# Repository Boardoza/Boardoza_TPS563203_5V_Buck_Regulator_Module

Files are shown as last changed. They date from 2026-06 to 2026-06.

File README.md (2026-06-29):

# Boardoza TPS563203 5V Regulator Module

The **Boardoza TPS563203 5V Regulator Module** is a compact and efficient DC-DC buck (step-down) converter designed to provide a stable **5V output** from a wide **7V–17V DC input** range. It is based on the **Texas Instruments TPS563203** synchronous buck regulator, known for its high efficiency and low quiescent current.

This module is ideal for powering **microcontrollers, sensors, communication modules, and embedded systems** that require a reliable 5V supply from higher-voltage sources such as adapters, batteries, or industrial power rails. Its small form factor and robust thermal performance make it suitable for both prototyping and production use.

## [Click here to purchase!](https://www.ozdisan.com/ureticiler/boardoza)

| Front Side | Back Side |
|:---:|:---:|
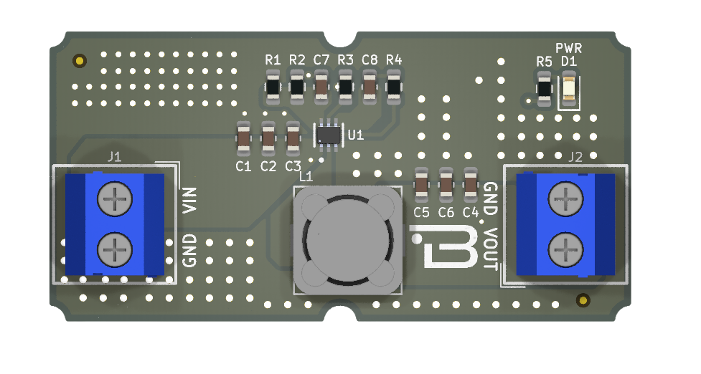
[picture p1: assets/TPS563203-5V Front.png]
TPS563203 5V Front
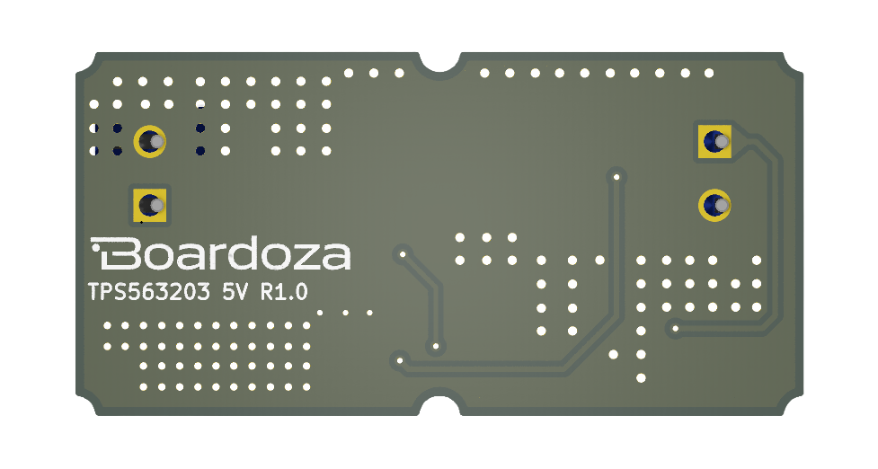
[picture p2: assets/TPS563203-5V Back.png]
TPS563203 5V Back
|  |  |

---

## Key Features

- **Wide Input Voltage Range:** Supports 7V to 17V DC input for flexible power sources.  
- **Stable 5V Output:** Provides a fixed and regulated 5V DC output suitable for logic and embedded systems.  
- **High Output Current Capability:** Delivers up to 2A continuous output current.  
- **High Efficiency Buck Topology:** Synchronous step-down conversion for reduced power loss.  
- **Low Quiescent Current:** Optimized for power-efficient designs with minimal standby consumption.  
- **Integrated Soft-Start:** Ensures controlled startup to protect connected loads.

---

## Technical Specifications

**Model:** TPS563203 5V  
**Manufacturer:** Boardoza  
**Manufacturer IC:** Texas Instruments  
**Regulator Type:** DC-DC Buck (Step-Down) Converter  
**Input Voltage:** 7V – 17V DC  
**Output Voltage:** 5V DC  
**Output Current:** Up to 2A  
**Switching Frequency:** 600 kHz  
**Quiescent Current:** 110 µA (typ.)  
**Soft-Start Time:** 1.4 ms (fixed)  
**Reference Voltage Accuracy:** ±1.5% (25°C), ±2% (–40°C to +125°C)  
**Operating Temperature:** –40°C to +125°C  
**Board Dimensions:** 20 mm × 40 mm  

---

## Board Pinout

### **( J1 ) Input Connector**

| Pin Number | Pin Name | Description |
|:---:|:---:|---|
| 1 | VIN | DC Input Voltage (7V – 17V) |
| 2 | GND | Ground |

### **( J2 ) Output Connector**

| Pin Number | Pin Name | Description |
|:---:|:---:|---|
| 1 | VOUT | Regulated +5V Output |
| 2 | GND | Ground |

---

## Board Dimensions

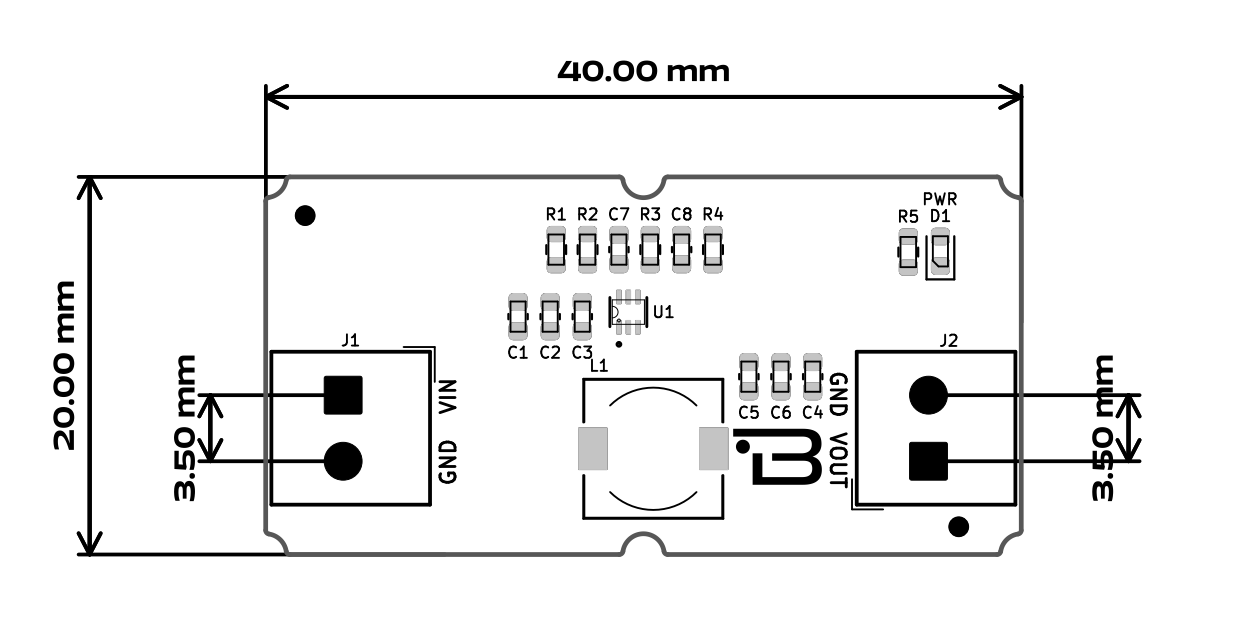
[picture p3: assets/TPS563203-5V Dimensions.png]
Board Dimensions
  

---

## Step Files

[Boardoza TPS563203 5V.step](./assets/TPS563203-5V%20Step.step)

---

## Datasheet

[TPS563203 5V Datasheet.pdf](./assets/TPS563203-5V%20Datasheet.pdf)

---

## Version History

- **V1.0.0** – Initial Release

---

## Support

- If you have any questions or need support, please contact **support@boardoza.com**

---

## **License**
### **Hardware Design**

[][cc-by-sa]

All hardware design files are licensed under [Creative Commons Attribution-ShareAlike 4.0 International License][cc-by-sa].

[cc-by-sa]: http://creativecommons.org/licenses/by-sa/4.0/
[cc-by-sa-shield]: https://img.shields.io/badge/License-CC%20BY--SA%204.0-lightgrey.svg

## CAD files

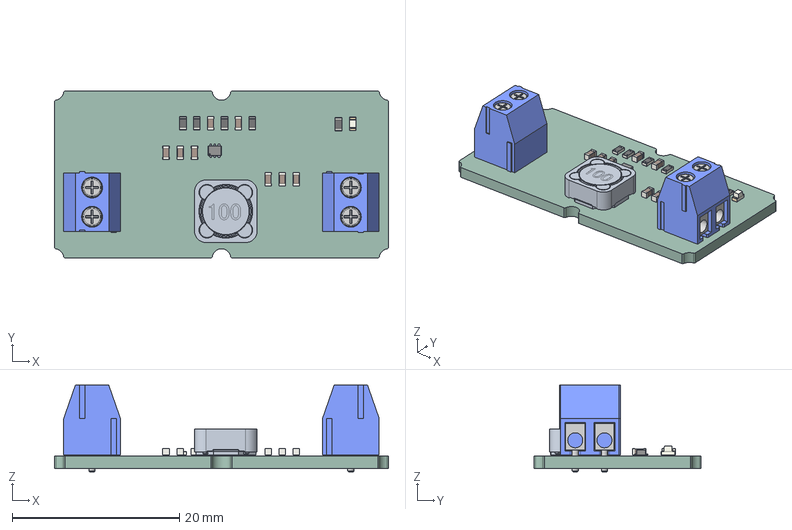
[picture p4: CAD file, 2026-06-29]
assets/TPS563203-5V Step.step
40.0 x 20.0 x 10.4 mm
Screw Terminal Block 3.5mm Blue 2-way x 2
LED_0603_1608Metric
R_0603_1608Metric x 5
C_0603_1608Metric x 8
SRR1260A-681K
TPS563203DRLR (1)
B-TPS563203-5V-BRK_PCB

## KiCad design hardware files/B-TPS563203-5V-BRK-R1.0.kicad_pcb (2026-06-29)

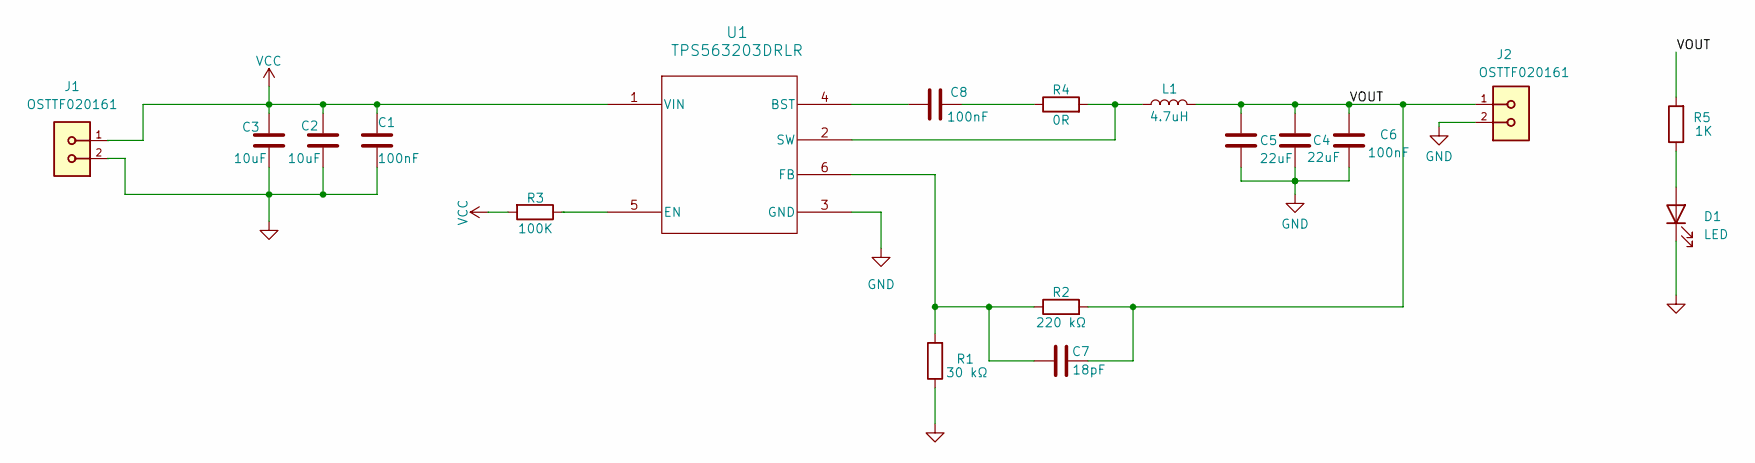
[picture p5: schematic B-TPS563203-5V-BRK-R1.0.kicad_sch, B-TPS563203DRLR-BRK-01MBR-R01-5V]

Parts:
C1, C6, C8: 100nF; C_0603_1608Metric; MPN CL10B104KB8NNNC
C2, C3: 10uF; C_0603_1608Metric; MPN MCF03MTX250106
C4, C5: 22uF; C_0603_1608Metric; MPN GRM188R61A226ME15D
C7: 18pF; C_0603_1608Metric; MPN MCF03JTN500180
D1: LED; LED_0603_1608Metric; MPN LTST-C190KRKT
J1, J2: OSTTF020161; OST_OSTTF020161; MPN DG350-3.5-02P-12-00AH
L1: 4.7uH; L_7.3x7.3_H4.5; MPN SRI0704-4R7M
R1: 30 kΩ; R_0603_1608Metric; MPN 0603SAJ0303T5E
R2: 220 kΩ; R_0603_1608Metric; MPN CRT03F7E2203
R3: 100K; R_0603_1608Metric; MPN CRT03F7E1003
R4: 0R; R_0603_1608Metric; MPN CRT03J7-R0R0
R5: 1K; R_0603_1608Metric; MPN RC0603JR-071KL
U1: TPS563203DRLR; SOT_07SDRLR_TEX; MPN TPS563203DRLR

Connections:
/VOUT: C4.1, C5.1, C6.1, C7.2, J2.1, L1.2, R2.2, R5.2
GND: C1.2, C2.2, C3.2, C4.2, C5.2, C6.2, D1.1 (K), J1.2, J2.2, R1.1, U1.3 (GND)
unnamed: C8.1, R4.1
unnamed: D1.2 (A), R5.1
unnamed: C8.2, U1.4 (BST)
unnamed: R3.1, U1.5 (EN)
unnamed: C7.1, R1.2, R2.1, U1.6 (FB)
unnamed: L1.1, R4.2, U1.2 (SW)
VCC: C1.1, C2.1, C3.1, J1.1, R3.2, U1.1 (VIN)

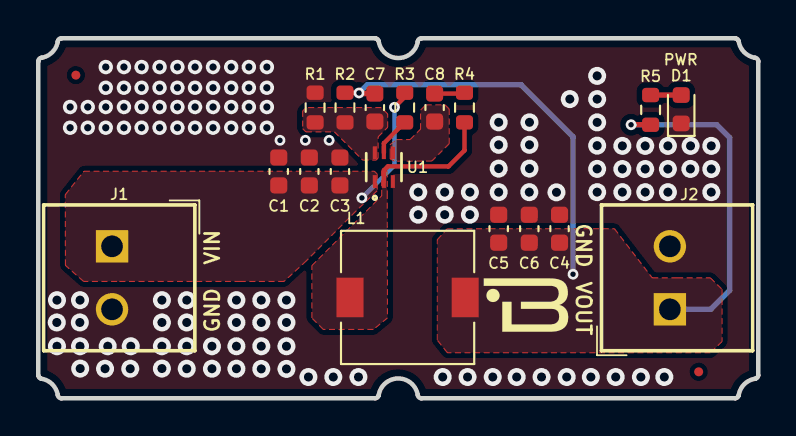
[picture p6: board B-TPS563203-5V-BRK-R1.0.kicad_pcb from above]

Board: 2 copper layers, 40.0 x 20.0 mm, 18 parts (0 on the bottom side), 9 nets.

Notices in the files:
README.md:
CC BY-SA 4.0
